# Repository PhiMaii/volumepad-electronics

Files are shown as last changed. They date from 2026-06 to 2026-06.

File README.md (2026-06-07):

# VolumePad STM32 PCB

Custom STM32-based PCB for the VolumePad project.

This board is intended for a haptic rotary input device with BLDC motor feedback, magnetic angle sensing, RGB LEDs, USB-C, buttons, strain sensing, and optional display support.

## Project status

Work in progress.

The current active development branch is `v2-redesign`.

The old version is kept on `v1-old`.

## Repository structure

    .
    ├── pcb/                 KiCad project files
    ├── docs/                Generated documentation, ignored by Git
    ├── fabrication/         Generated manufacturing files, ignored by Git
    ├── scripts/             Helper scripts
    ├── config.kibot.yaml    KiBot output configuration
    └── .github/workflows/   GitHub Actions automation

## PCB features

Planned / included hardware:

- STM32F405RGT6 microcontroller
- USB-C power and USB FS device connection
- TMC6300 BLDC motor driver
- MT6701 magnetic angle sensor
- WS2812B / SK6812 addressable RGB LEDs
- HX711-based strain sensing
- SWD programming connector
- Optional SPI display connection
- 4-layer PCB stackup

## KiCad project

Open the KiCad project from:

    open pcb/volumepad-stm32-pcb.kicad_pro

Main project files:

    pcb/volumepad-stm32-pcb.kicad_pro
    pcb/volumepad-stm32-pcb.kicad_sch
    pcb/volumepad-stm32-pcb.kicad_pcb

## KiBot automation

This repo uses KiBot through GitHub Actions to automatically generate documentation and manufacturing files.

Generated outputs include:

- Schematic PDF
- Gerber files
- Drill files
- BOM
- Pick-and-place position files

The workflow runs on changes to the PCB project or KiBot configuration.

Generated files are uploaded as GitHub Actions artifacts and are not committed to the repository.

## Generated files

Local generated outputs may appear in:

    docs/
    fabrication/

These files are intentionally ignored by Git.

## Notes

This PCB is still under active development and should not be considered production-ready yet.

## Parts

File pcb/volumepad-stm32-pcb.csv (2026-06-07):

Reference | Qty | Value | DNP | Exclude from BOM | Exclude from Board | Footprint | Datasheet | LCSC
C201,C204,C207,C301,C302,C303,C304,C307,C310,C501,C502,C503,C505,C506,C601,C701,C703,C704,C705,C801,C802,C803,C804,C805,C806,C807,C808,C809,C810,C811,C812,C813,C814,C815,C816,C817,C818,C819,C820,C821,C822,C823,C824,C825,C826,C827,C828,C829,C830,C831,C832,C833,C834,C835,C901 | 55 | 100n |  |  |  | Capacitor_SMD:C_0603_1608Metric |  | C42405541
C202,C205,C206,C504,C507,C702 | 6 | 10u |  |  |  | Capacitor_SMD:C_0805_2012Metric
C203 | 1 | 47u |  |  |  | Capacitor_SMD:C_1206_3216Metric
C305 | 1 | 4u7 |  |  |  | Capacitor_SMD:C_0805_2012Metric
C306,C902 | 2 | 1u |  |  |  | Capacitor_SMD:C_0603_1608Metric
C308,C309 | 2 | 2u2 |  |  |  | Capacitor_SMD:C_0805_2012Metric
C311,C312 | 2 | 18p |  |  |  | Capacitor_SMD:C_0603_1608Metric
C602 | 1 | 470u |  |  |  | Capacitor_SMD:CP_Elec_6.3x5.8 | 10 V
C706 | 1 | 100u |  |  |  | Capacitor_SMD:CP_Elec_5x5.8
D201 | 1 | D_TVS |  |  |  | Diode_SMD:D_SOD-123 |  | C2445454
D202 | 1 | RED |  |  |  | LED_SMD:LED_0603_1608Metric
D301 | 1 | BLUE |  |  |  | LED_SMD:LED_0603_1608Metric
D701 | 1 | ORANGE |  |  |  | LED_SMD:LED_0603_1608Metric
D804,D805,D806,D807,D808,D809,D810,D811,D812,D813,D814,D815,D816,D817,D818,D819,D820,D821,D822,D823,D824,D825,D826,D827,D828,D829,D830,D831,D832,D833,D834,D835 | 32 | WS2812B-2020 |  |  |  | LED_SMD:LED_WS2812B-2020_PLCC4_2.0x2.0mm | https://cdn-shop.adafruit.com/product-files/4684/4684_WS2812B-2020_V1.3_EN.pdf
F201 | 1 | Polyfuse |  |  |  | Fuse:Fuse_1206_3216Metric
FB201 | 1 | 600R@100MHz 2A |  |  |  | Inductor_SMD:L_0805_2012Metric | BLM21PG600SN1D
FB202 | 1 | 600R@100MHz, >=200mA, 0603 |  |  |  | Inductor_SMD:L_0603_1608Metric
J401 | 1 | USB_C_Receptacle_USB2.0_14P |  |  |  | Connector_USB:USB_C_Receptacle_GCT_USB4105-xx-A_16P_TopMnt_Horizontal | https://www.usb.org/sites/default/files/documents/usb_type-c.zip
J701 | 1 | Conn_01x03_Pin |  |  |  | Connector_JST:JST_SH_SM03B-SRSS-TB_1x03-1MP_P1.00mm_Horizontal
L501 | 1 | 3u3 |  |  |  | Inductor_SMD:L_0805_2012Metric
LED801,LED802,LED803 | 3 | MX_SK6812MINI-E |  |  |  | PCM_marbastlib-mx:LED_MX_6028R
MX501,MX502,MX503 | 3 | MX_SW_solder |  |  |  | PCM_marbastlib-mx:SW_MX_1u
Q501 | 1 | MMBT4403 |  |  |  | Package_TO_SOT_SMD:SOT-23
Q901 | 1 | AO3400A |  |  |  | Package_TO_SOT_SMD:SOT-23 | http://www.aosmd.com/pdfs/datasheet/AO3400A.pdf
R201 | 1 | 1k5 |  |  |  | Resistor_SMD:R_0603_1608Metric
R301,R302,R501,R504,R702,R901,R902 | 7 | 10k |  |  |  | Resistor_SMD:R_0603_1608Metric
R303,R304,R305,R306 | 4 | 22 |  |  |  | Resistor_SMD:R_0603_1608Metric
R307 | 1 | 1.5k |  |  |  | Resistor_SMD:R_0603_1608Metric
R401,R402 | 2 | 5k1 |  |  |  | Resistor_SMD:R_0603_1608Metric
R502,R503 | 2 | 100R |  |  |  | Resistor_SMD:R_0603_1608Metric
R505 | 1 | 8k2 |  |  |  | Resistor_SMD:R_0603_1608Metric
R601 | 1 | 330R |  |  |  | Resistor_SMD:R_0603_1608Metric
R701 | 1 | 2k2 |  |  |  | Resistor_SMD:R_0603_1608Metric
R703,R704,R705,R706,R707,R708,R710,R907 | 8 | 100k |  |  |  | Resistor_SMD:R_0603_1608Metric
R709,R903,R904,R905,R906 | 5 | 100 |  |  |  | Resistor_SMD:R_0603_1608Metric
RSG501,RSG502,RSG503,RSG504 | 4 | 330R |  |  |  | Resistor_SMD:R_2512_6332Metric
SW301 | 1 | RESET |  |  |  | Button_Switch_SMD:SW_Push_SPST_NO_Alps_SKRK
SW302 | 1 | BOOT0 |  |  |  | Button_Switch_SMD:SW_Push_SPST_NO_Alps_SKRK
U202 | 1 | AP1117-33 |  |  |  | Package_TO_SOT_SMD:SOT-223-3_TabPin2 | http://www.diodes.com/datasheets/AP1117.pdf
U301 | 1 | STM32F405RGTx |  |  |  | Package_QFP:LQFP-64_10x10mm_P0.5mm | https://www.st.com/resource/en/datasheet/stm32f405rg.pdf
U401 | 1 | USBLC6-2SC6 |  |  |  | Package_TO_SOT_SMD:SOT-23-6 | https://www.st.com/resource/en/datasheet/usblc6-2.pdf
U501 | 1 | MT6701CT |  |  |  | Package_SO:SO-8_3.9x4.9mm_P1.27mm | https://www.magntek.com.cn/upload/MT6701_Rev.1.5.pdf
U502 | 1 | HX711 |  |  |  | Package_SO:SOIC-16_3.9x9.9mm_P1.27mm | https://web.archive.org/web/20220615044707/https://akizukidenshi.com/download/ds/avia/hx711.pdf
U601 | 1 | 74AHCT1G125 |  |  |  | Package_TO_SOT_SMD:SOT-23-5 | http://www.ti.com/lit/sg/scyt129e/scyt129e.pdf
U701 | 1 | TMC6300-LA |  |  |  | TMC6300:QFN40P300X300X90-21N
Y301 | 1 | 8 MHz |  |  |  | Crystal:Crystal_SMD_3225-4Pin_3.2x2.5mm

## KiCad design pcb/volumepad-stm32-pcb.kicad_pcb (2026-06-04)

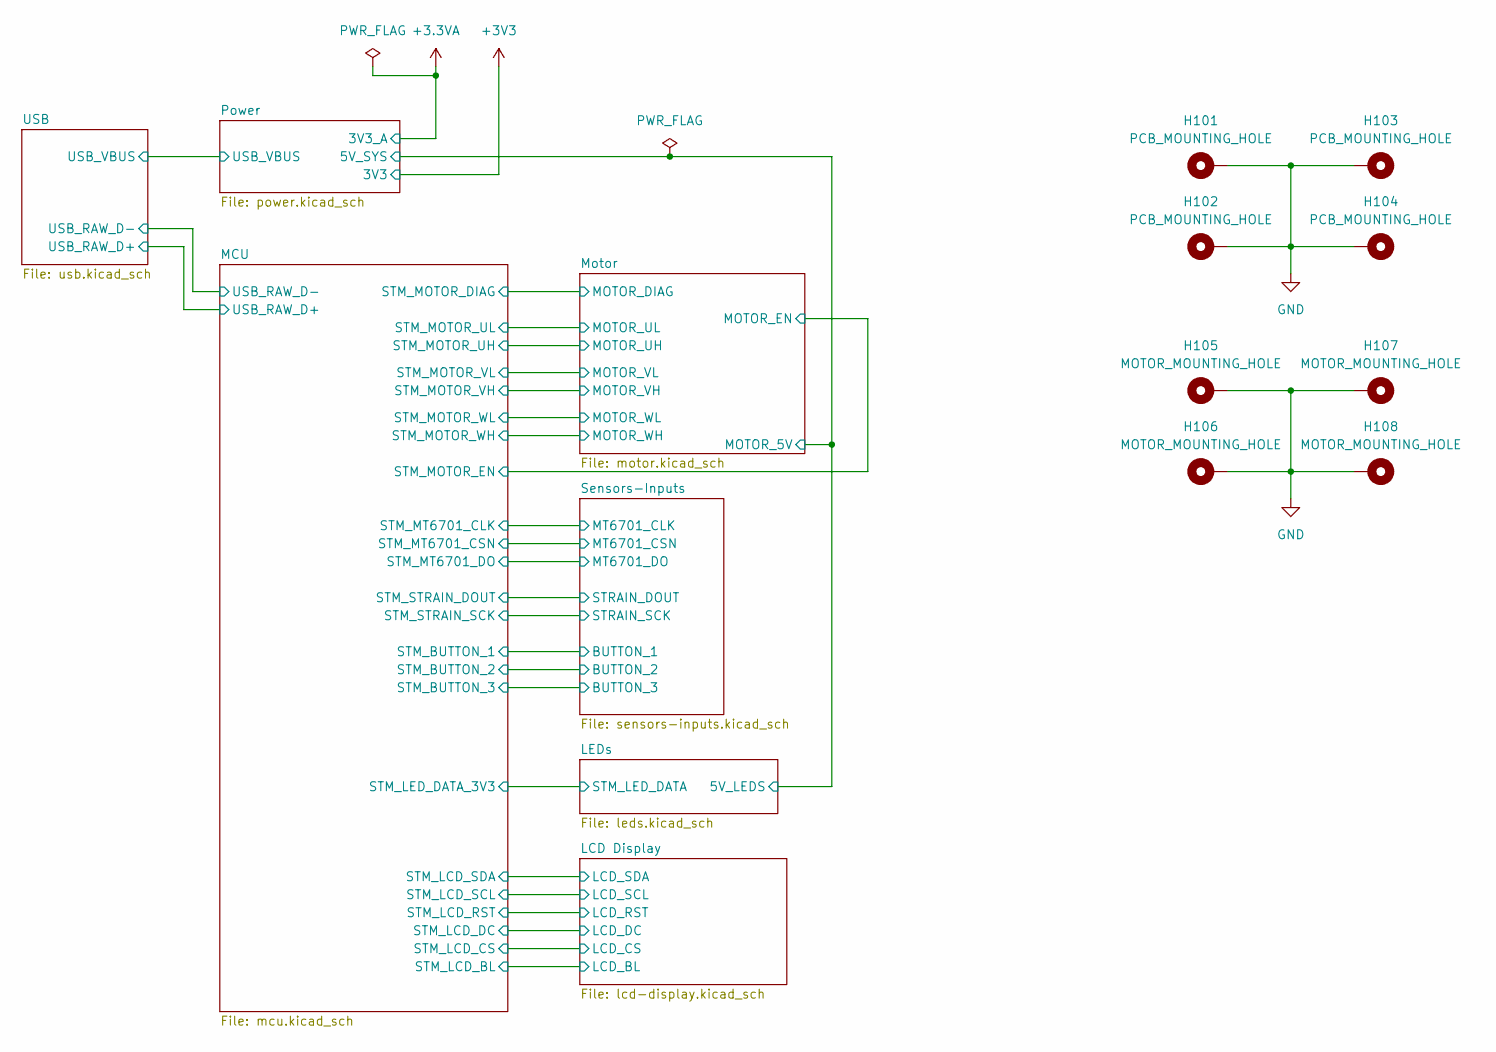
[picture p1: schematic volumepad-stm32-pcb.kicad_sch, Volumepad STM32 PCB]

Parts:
H101, H102, H103, H104: PCB_MOUNTING_HOLE; MountingHole_3mm_Pad_Via
H105, H106, H107, H108: MOTOR_MOUNTING_HOLE; MountingHole_2.5mm_Pad_Via

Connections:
GND: H101.1 (1_1), H102.1 (1_1), H103.1 (1_1), H104.1 (1_1), H105.1 (1_1), H106.1 (1_1), H107.1 (1_1), H108.1 (1_1); also elsewhere on the board

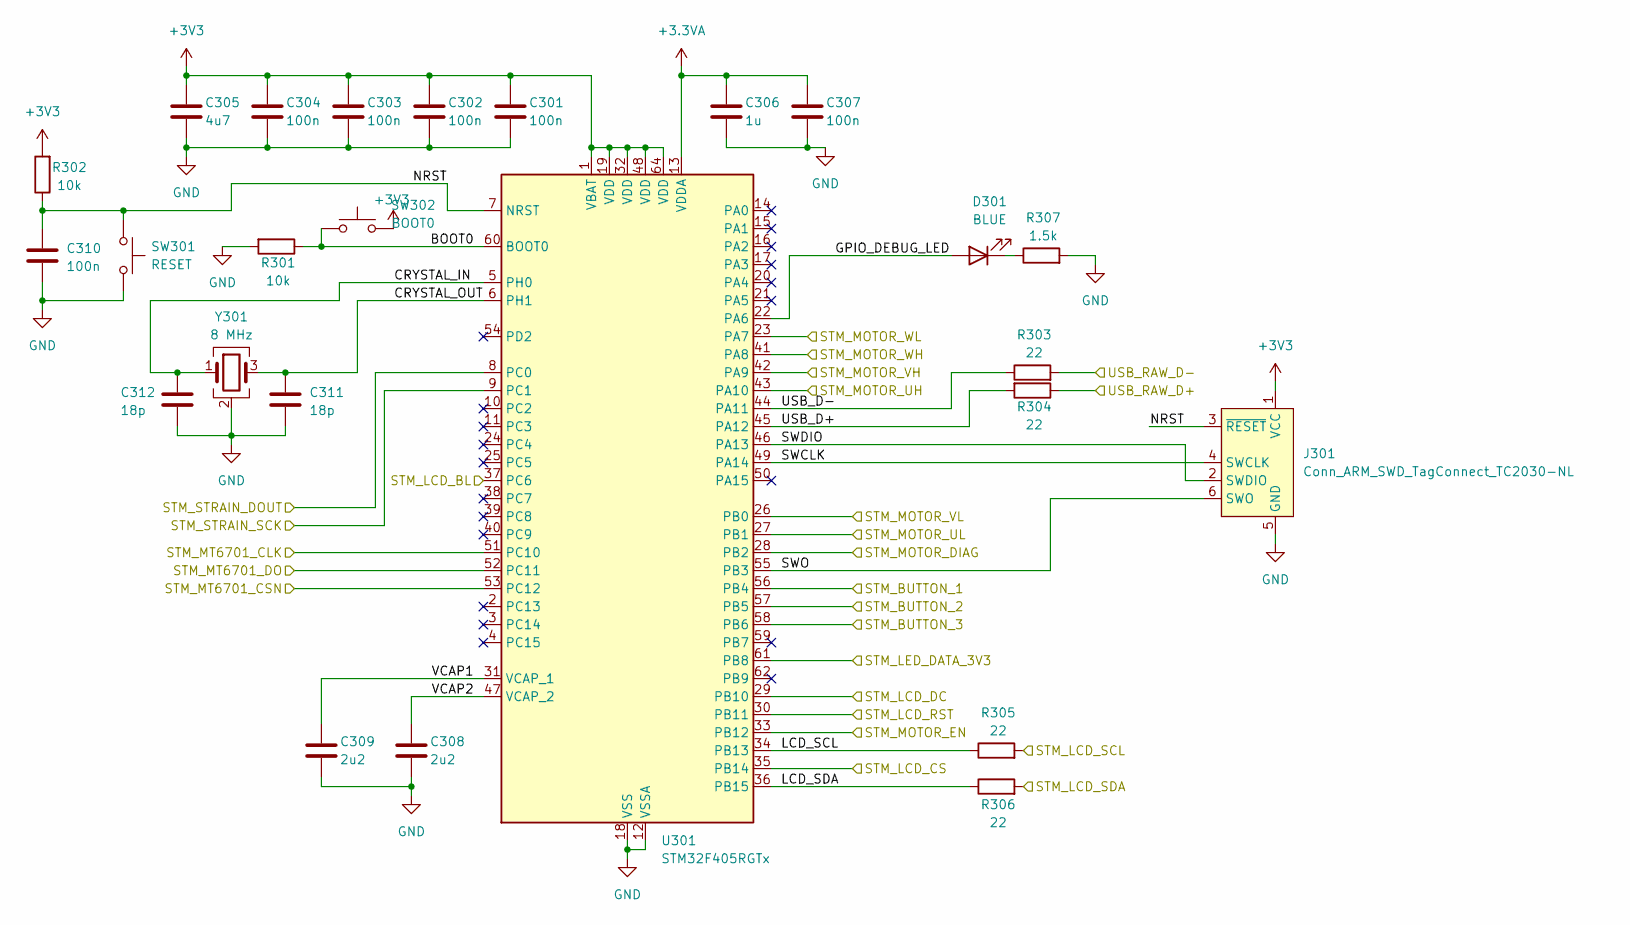
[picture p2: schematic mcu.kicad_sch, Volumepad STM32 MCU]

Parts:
C301, C302, C303, C304, C307, C310: 100n; C_0603_1608Metric; LCSC C42405541
C305: 4u7; C_0805_2012Metric
C306: 1u; C_0603_1608Metric
C308, C309: 2u2; C_0805_2012Metric
C311, C312: 18p; C_0603_1608Metric
D301: BLUE; LED_0603_1608Metric
J301: Conn_ARM_SWD_TagConnect_TC2030-NL; Tag-Connect_TC2030-IDC-NL_2x03_P1.27mm_Vertical
R301, R302: 10k; R_0603_1608Metric
R303, R304, R305, R306: 22; R_0603_1608Metric
R307: 1.5k; R_0603_1608Metric
SW301: RESET; SW_Push_SPST_NO_Alps_SKRK
SW302: BOOT0; SW_Push_SPST_NO_Alps_SKRK
U301: STM32F405RGTx; LQFP-64_10x10mm_P0.5mm; LCSC Part # C15742
Y301: 8 MHz; Crystal_SMD_3225-4Pin_3.2x2.5mm

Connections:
+3.3VA: C306.1, C307.1, U301.13 (VDDA); also elsewhere on the board
+3V3: C301.1, C302.1, C303.1, C304.1, C305.1, J301.1 (VCC), R302.2, SW302.1, U301.1 (VBAT), U301.19 (VDD), U301.32 (VDD), U301.48 (VDD), U301.64 (VDD); also elsewhere on the board
/LCD Display/LCD_BL: U301.37 (PC6); also elsewhere on the board
/LCD Display/LCD_CS: U301.35 (PB14); also elsewhere on the board
/LCD Display/LCD_DC: U301.29 (PB10); also elsewhere on the board
/LCD Display/LCD_RST: U301.30 (PB11); also elsewhere on the board
/LCD Display/LCD_SCL: R305.2; also elsewhere on the board
/LCD Display/LCD_SDA: R306.2; also elsewhere on the board
/LEDs/STM_LED_DATA: U301.61 (PB8); also elsewhere on the board
/MCU/BOOT0: R301.1, SW302.2, U301.60 (BOOT0)
/MCU/CRYSTAL_IN: C312.2, U301.5 (PH0), Y301.1
/MCU/CRYSTAL_OUT: C311.1, U301.6 (PH1), Y301.3
/MCU/GPIO_DEBUG_LED: D301.2 (A), U301.22 (PA6)
/MCU/LCD_SCL: R305.1, U301.34 (PB13)
/MCU/LCD_SDA: R306.1, U301.36 (PB15)
/MCU/NRST: C310.1, J301.3 (~RESET), R302.1, SW301.1, U301.7 (NRST)
/MCU/STM_BUTTON_1: U301.56 (PB4); also elsewhere on the board
/MCU/STM_BUTTON_2: U301.57 (PB5); also elsewhere on the board
/MCU/STM_BUTTON_3: U301.58 (PB6); also elsewhere on the board
/MCU/STM_MOTOR_EN: U301.33 (PB12); also elsewhere on the board
/MCU/STM_MOTOR_UH: U301.43 (PA10); also elsewhere on the board
/MCU/STM_MOTOR_UL: U301.27 (PB1); also elsewhere on the board
/MCU/STM_MOTOR_VH: U301.42 (PA9); also elsewhere on the board
/MCU/STM_MOTOR_VL: U301.26 (PB0); also elsewhere on the board
/MCU/STM_MOTOR_WH: U301.41 (PA8); also elsewhere on the board
/MCU/STM_MOTOR_WL: U301.23 (PA7); also elsewhere on the board
/MCU/STM_MT6701_CLK: U301.51 (PC10); also elsewhere on the board
/MCU/STM_MT6701_CSN: U301.53 (PC12); also elsewhere on the board
/MCU/STM_MT6701_DO: U301.52 (PC11); also elsewhere on the board
/MCU/STM_STRAIN_DOUT: U301.8 (PC0); also elsewhere on the board
/MCU/STM_STRAIN_SCK: U301.9 (PC1); also elsewhere on the board
/MCU/SWCLK: J301.4 (SWCLK), U301.49 (PA14)
/MCU/SWDIO: J301.2 (SWDIO), U301.46 (PA13)
/MCU/SWO: J301.6 (SWO), U301.55 (PB3)
/MCU/USB_D+: R304.2, U301.45 (PA12)
/MCU/USB_D-: R303.1, U301.44 (PA11)
/MCU/USB_RAW_D+: R304.1; also elsewhere on the board
/MCU/USB_RAW_D-: R303.2; also elsewhere on the board
/MCU/VCAP1: C309.1, U301.31 (VCAP_1)
/MCU/VCAP2: C308.1, U301.47 (VCAP_2)
/Motor/MOTOR_DIAG: U301.28 (PB2); also elsewhere on the board
GND: C301.2, C302.2, C303.2, C304.2, C305.2, C306.2, C307.2, C308.2, C309.2, C310.2, C311.2, C312.1, J301.5 (GND), R301.2, R307.2, SW301.2, U301.12 (VSSA), U301.18 (VSS), U301.63 (VSS), Y301.2 (G), Y301.4 (G); also elsewhere on the board
unnamed: D301.1 (K), R307.1

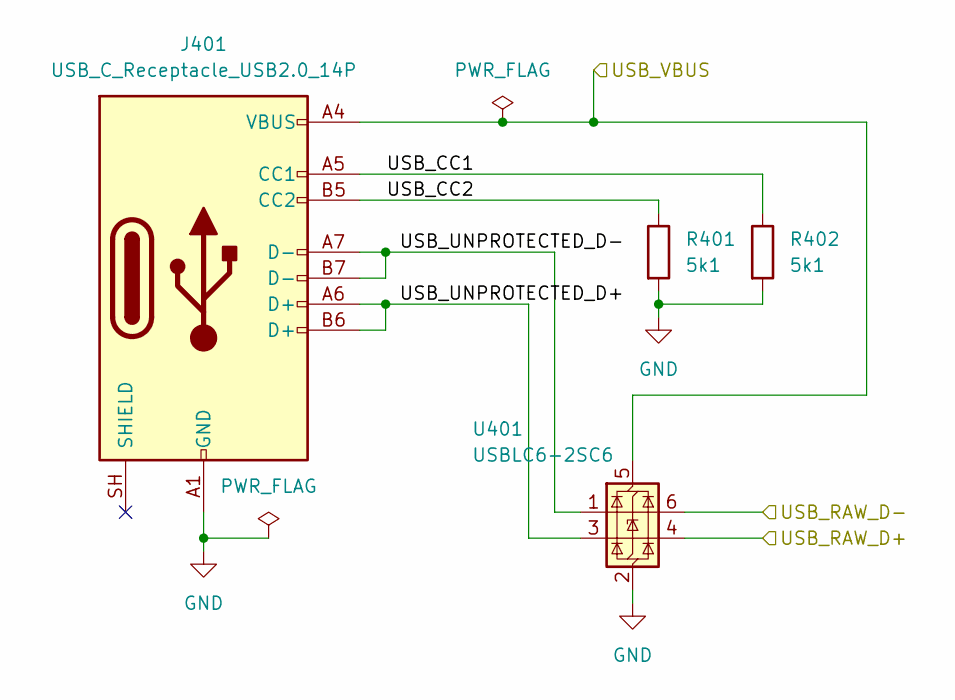
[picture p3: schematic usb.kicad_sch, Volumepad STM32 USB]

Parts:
J401: USB_C_Receptacle_USB2.0_14P; USB_C_Receptacle_GCT_USB4105-xx-A_16P_TopMnt_Horizontal
R401, R402: 5k1; R_0603_1608Metric
U401: USBLC6-2SC6; SOT-23-6

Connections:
/MCU/USB_RAW_D+: U401.4 (I/O2); also elsewhere on the board
/MCU/USB_RAW_D-: U401.6 (I/O1); also elsewhere on the board
/Power/USB_VBUS: J401.A4 (VBUS), J401.A9 (VBUS), J401.B4 (VBUS), J401.B9 (VBUS), U401.5 (VBUS); also elsewhere on the board
/USB/USB_CC1: J401.A5 (CC1), R402.1
/USB/USB_CC2: J401.B5 (CC2), R401.1
/USB/USB_UNPROTECTED_D+: J401.A6 (D+), J401.B6 (D+), U401.3 (I/O2)
/USB/USB_UNPROTECTED_D-: J401.A7 (D-), J401.B7 (D-), U401.1 (I/O1)
GND: J401.A1 (GND), J401.A12 (GND), J401.B1 (GND), J401.B12 (GND), R401.2, R402.2, U401.2 (GND); also elsewhere on the board

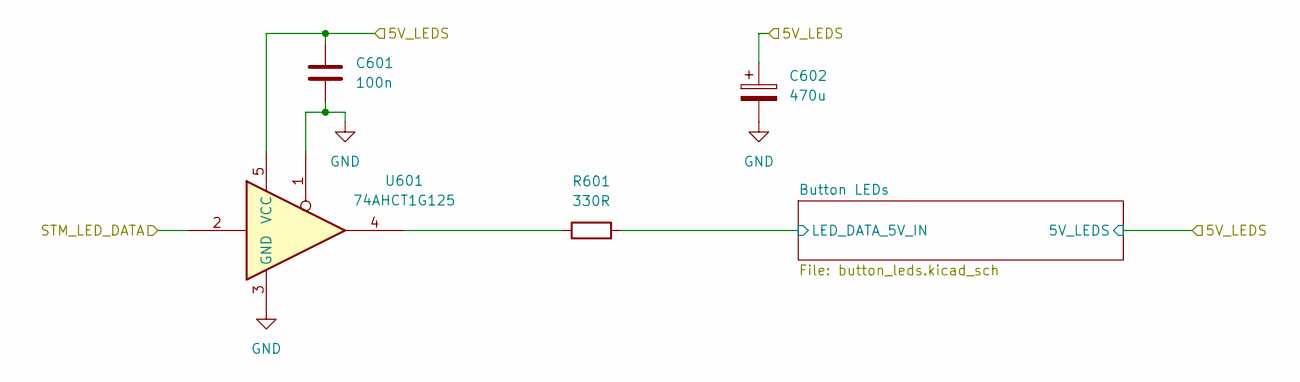
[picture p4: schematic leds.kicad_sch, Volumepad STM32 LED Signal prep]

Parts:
C601: 100n; C_0603_1608Metric; LCSC C42405541
C602: 470u; CP_Elec_6.3x5.8
R601: 330R; R_0603_1608Metric
U601: 74AHCT1G125; SOT-23-5

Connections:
/LEDs/Button LEDs/LED_DATA_5V_IN: R601.2; also elsewhere on the board
/LEDs/STM_LED_DATA: U601.2; also elsewhere on the board
/Power/5V_SYS: C601.1, C602.1, U601.5 (VCC); also elsewhere on the board
GND: C601.2, C602.2, U601.1, U601.3 (GND); also elsewhere on the board
unnamed: R601.1, U601.4

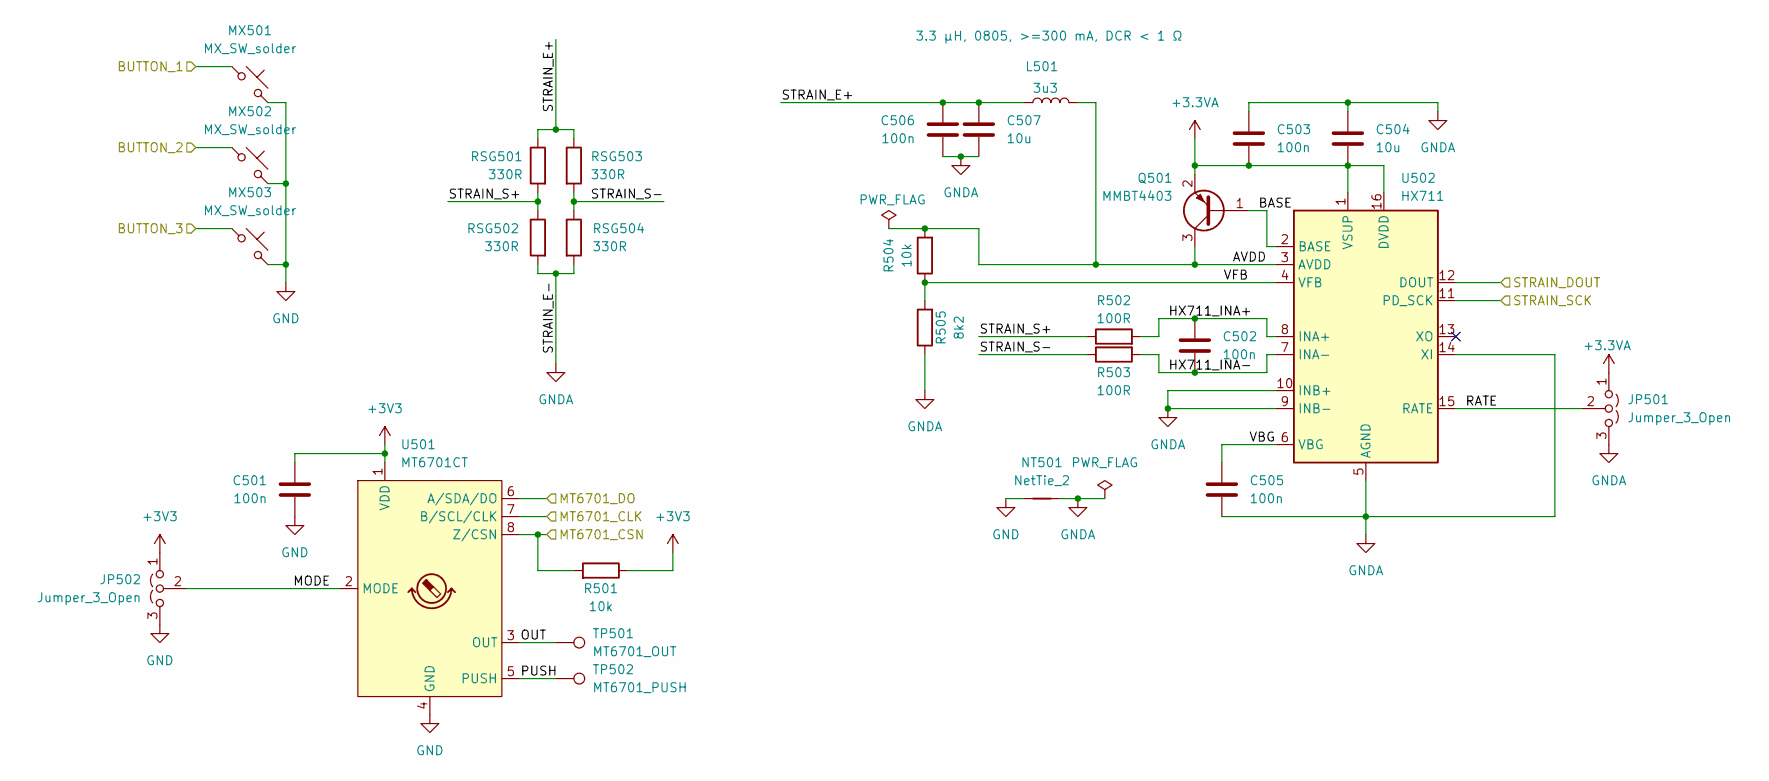
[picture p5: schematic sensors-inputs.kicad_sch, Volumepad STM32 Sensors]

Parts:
C501, C502, C503, C505, C506: 100n; C_0603_1608Metric; LCSC C42405541
C504, C507: 10u; C_0805_2012Metric
JP501, JP502: Jumper_3_Open; SolderJumper-3_P1.3mm_Open_RoundedPad1.0x1.5mm
L501: 3u3; L_0805_2012Metric
MX501, MX502, MX503: MX_SW_solder; SW_MX_1u
NT501: NetTie_2; NetTie-2_SMD_Pad0.5mm
Q501: MMBT4403; SOT-23
R501, R504: 10k; R_0603_1608Metric
R502, R503: 100R; R_0603_1608Metric
R505: 8k2; R_0603_1608Metric
RSG501, RSG502, RSG503, RSG504: 330R; R_2512_6332Metric
TP501: MT6701_OUT; TestPoint_Pad_D1.0mm
TP502: MT6701_PUSH; TestPoint_Pad_D1.0mm
U501: MT6701CT; SO-8_3.9x4.9mm_P1.27mm
U502: HX711; SOIC-16_3.9x9.9mm_P1.27mm

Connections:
+3.3VA: C503.2, C504.2, JP501.1 (A), Q501.2 (E), U502.1 (VSUP), U502.16 (DVDD); also elsewhere on the board
+3V3: C501.1, JP502.1 (A), R501.1, U501.1 (VDD); also elsewhere on the board
/MCU/STM_BUTTON_1: MX501.1; also elsewhere on the board
/MCU/STM_BUTTON_2: MX502.1; also elsewhere on the board
/MCU/STM_BUTTON_3: MX503.1; also elsewhere on the board
/MCU/STM_MT6701_CLK: U501.7 (B/SCL/CLK); also elsewhere on the board
/MCU/STM_MT6701_CSN: R501.2, U501.8 (Z/CSN); also elsewhere on the board
/MCU/STM_MT6701_DO: U501.6 (A/SDA/DO); also elsewhere on the board
/MCU/STM_STRAIN_DOUT: U502.12 (DOUT); also elsewhere on the board
/MCU/STM_STRAIN_SCK: U502.11 (PD_SCK); also elsewhere on the board
/Sensors-Inputs/AVDD: L501.1, Q501.3 (C), R504.2, U502.3 (AVDD)
/Sensors-Inputs/BASE: Q501.1 (B), U502.2 (BASE)
/Sensors-Inputs/HX711_INA+: C502.1, R502.2, U502.8 (INA+)
/Sensors-Inputs/HX711_INA-: C502.2, R503.2, U502.7 (INA-)
/Sensors-Inputs/MODE: JP502.2 (C), U501.2 (MODE)
/Sensors-Inputs/OUT: TP501.1 (1_1), U501.3 (OUT)
/Sensors-Inputs/PUSH: TP502.1 (1_1), U501.5 (PUSH)
/Sensors-Inputs/RATE: JP501.2 (C), U502.15 (RATE)
/Sensors-Inputs/STRAIN_E+: C506.1, C507.1, L501.2, RSG501.1, RSG503.1
/Sensors-Inputs/STRAIN_S+: R502.1, RSG501.2, RSG502.1
/Sensors-Inputs/STRAIN_S-: R503.1, RSG503.2, RSG504.1
/Sensors-Inputs/VBG: C505.1, U502.6 (VBG)
/Sensors-Inputs/VFB: R504.1, R505.2, U502.4 (VFB)
GND: C501.2, JP502.3 (B), MX501.2, MX502.2, MX503.2, NT501.1, U501.4 (GND); also elsewhere on the board
GNDA: C503.1, C504.1, C505.2, C506.2, C507.2, JP501.3 (B), NT501.2, R505.1, RSG502.2, RSG504.2, U502.5 (AGND), U502.9 (INB-), U502.10 (INB+), U502.14 (XI)

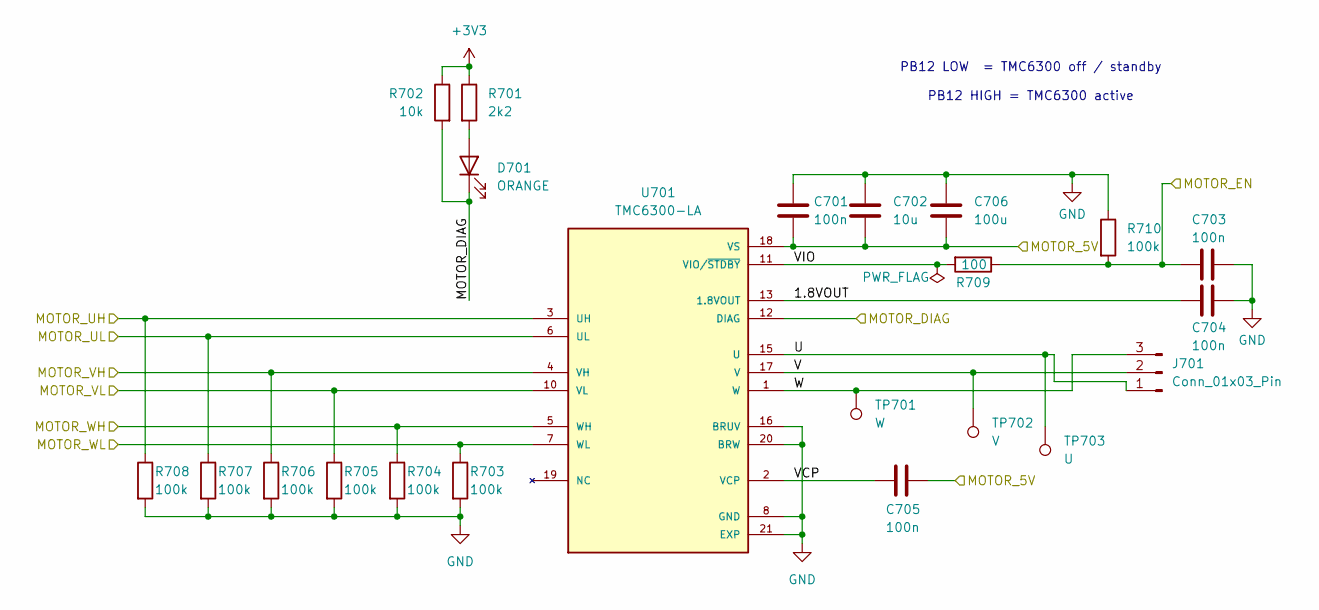
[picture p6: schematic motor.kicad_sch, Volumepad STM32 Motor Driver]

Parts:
C701, C703, C704, C705: 100n; C_0603_1608Metric
C702: 10u; C_0805_2012Metric
C706: 100u; CP_Elec_5x5.8
D701: ORANGE; LED_0603_1608Metric
J701: Conn_01x03_Pin; JST_SH_SM03B-SRSS-TB_1x03-1MP_P1.00mm_Horizontal
R701: 2k2; R_0603_1608Metric
R702: 10k; R_0603_1608Metric
R703, R704, R705, R706, R707, R708, R710: 100k; R_0603_1608Metric
R709: 100; R_0603_1608Metric
TP701: W; TestPoint_Pad_D1.0mm
TP702: V; TestPoint_Pad_D1.0mm
TP703: U; TestPoint_Pad_D1.0mm
U701: TMC6300-LA; QFN40P300X300X90-21N; PARTREV 1.08

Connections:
+3V3: R701.1, R702.1; also elsewhere on the board
/MCU/STM_MOTOR_EN: C703.1, R709.1, R710.2; also elsewhere on the board
/MCU/STM_MOTOR_UH: R708.1, U701.3 (UH); also elsewhere on the board
/MCU/STM_MOTOR_UL: R707.1, U701.6 (UL); also elsewhere on the board
/MCU/STM_MOTOR_VH: R706.1, U701.4 (VH); also elsewhere on the board
/MCU/STM_MOTOR_VL: R705.1, U701.10 (VL); also elsewhere on the board
/MCU/STM_MOTOR_WH: R704.1, U701.5 (WH); also elsewhere on the board
/MCU/STM_MOTOR_WL: R703.1, U701.7 (WL); also elsewhere on the board
/Motor/1.8VOUT: C704.2, U701.13 (1.8VOUT)
/Motor/MOTOR_DIAG: D701.1 (K), R702.2, U701.12 (DIAG); also elsewhere on the board
/Motor/U: J701.1, TP703.1 (1_1), U701.15 (U)
/Motor/V: J701.2, TP702.1 (1_1), U701.17 (V)
/Motor/VCP: C705.1, U701.2 (VCP)
/Motor/VIO: R709.2, U701.11 (VIO/~STDBY)
/Motor/W: J701.3, TP701.1 (1_1), U701.1 (W)
/Power/5V_SYS: C701.2, C702.2, C705.2, C706.2, U701.18 (VS); also elsewhere on the board
GND: C701.1, C702.1, C703.2, C704.1, C706.1, R703.2, R704.2, R705.2, R706.2, R707.2, R708.2, R710.1, U701.8 (GND), U701.9 (GND), U701.14 (GND), U701.16 (BRUV), U701.20 (BRW), U701.21 (EXP); also elsewhere on the board
unnamed: D701.2 (A), R701.2

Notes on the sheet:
PB12 LOW = TMC6300 off / standby PB12 HIGH = TMC6300 active

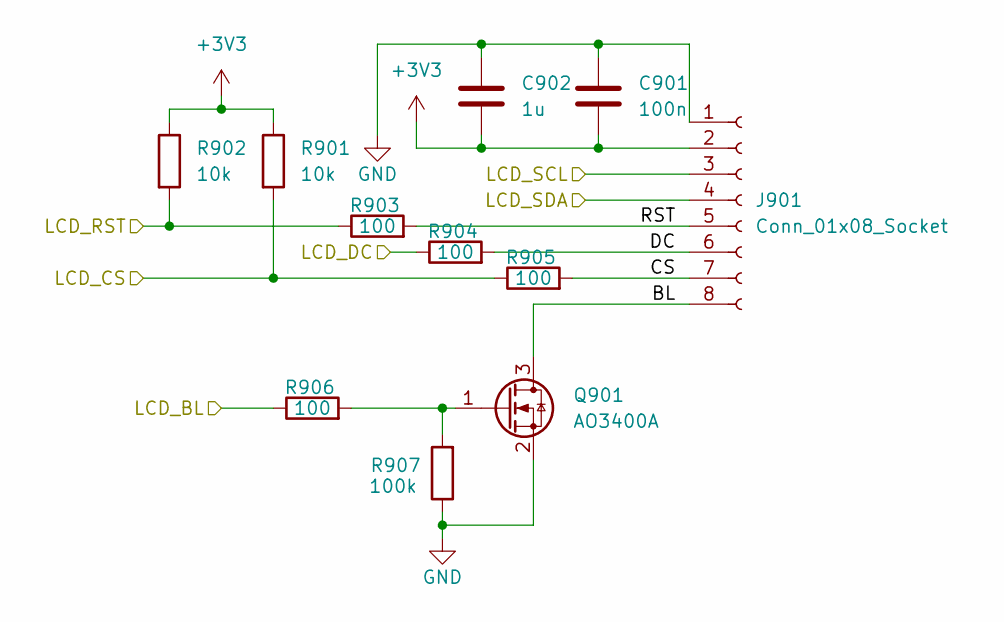
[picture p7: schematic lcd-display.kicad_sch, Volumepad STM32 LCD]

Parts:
C901: 100n; C_0603_1608Metric
C902: 1u; C_0603_1608Metric
J901: Conn_01x08_Socket; PinHeader_1x08_P2.54mm_Vertical
Q901: AO3400A; SOT-23
R901, R902: 10k; R_0603_1608Metric
R903, R904, R905, R906: 100; R_0603_1608Metric
R907: 100k; R_0603_1608Metric

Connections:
+3V3: C901.2, C902.2, J901.2 (VCC), R901.1, R902.1; also elsewhere on the board
/LCD Display/BL: J901.8 (BL), Q901.3 (D)
/LCD Display/CS: J901.7 (CS), R905.2
/LCD Display/DC: J901.6 (DC), R904.2
/LCD Display/LCD_BL: R906.1; also elsewhere on the board
/LCD Display/LCD_CS: R901.2, R905.1; also elsewhere on the board
/LCD Display/LCD_DC: R904.1; also elsewhere on the board
/LCD Display/LCD_RST: R902.2, R903.1; also elsewhere on the board
/LCD Display/LCD_SCL: J901.3 (SCL); also elsewhere on the board
/LCD Display/LCD_SDA: J901.4 (SDA); also elsewhere on the board
/LCD Display/RST: J901.5 (RST), R903.2
GND: C901.1, C902.1, J901.1 (GND), Q901.2 (S), R907.1; also elsewhere on the board
unnamed: Q901.1 (G), R906.2, R907.2

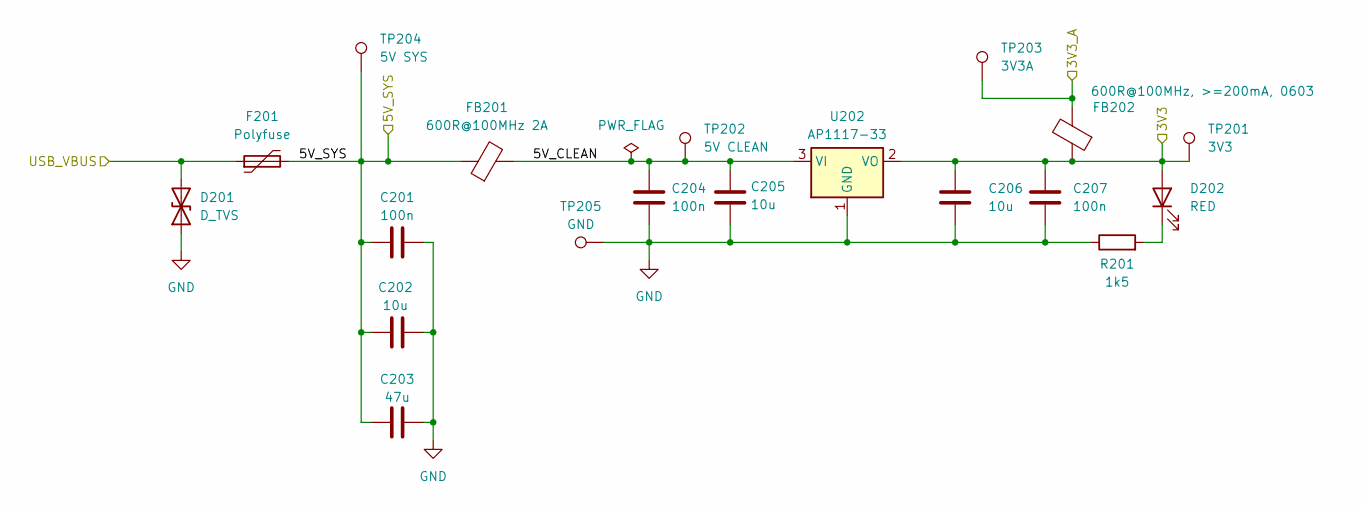
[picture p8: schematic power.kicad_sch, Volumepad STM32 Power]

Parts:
C201, C204, C207: 100n; C_0603_1608Metric; LCSC C42405541
C202, C205, C206: 10u; C_0805_2012Metric
C203: 47u; C_1206_3216Metric
D201: D_TVS; D_SOD-123; LCSC C2445454
D202: RED; LED_0603_1608Metric
F201: Polyfuse; Fuse_1206_3216Metric; LCSC Part # C70082
FB201: 600R@100MHz 2A; L_0805_2012Metric
FB202: 600R@100MHz, >=200mA, 0603; L_0603_1608Metric
R201: 1k5; R_0603_1608Metric
TP201: 3V3; TestPoint_Pad_D1.0mm
TP202: 5V CLEAN; TestPoint_Pad_D1.0mm
TP203: 3V3A; TestPoint_Pad_D1.0mm
TP204: 5V SYS; TestPoint_Pad_D1.0mm
TP205: GND; TestPoint_Pad_D1.0mm
U202: AP1117-33; SOT-223-3_TabPin2

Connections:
+3.3VA: FB202.2, TP203.1 (1_1); also elsewhere on the board
+3V3: C206.1, C207.2, D202.2 (A), FB202.1, TP201.1 (1_1), U202.2 (VO); also elsewhere on the board
/Power/5V_CLEAN: C204.1, C205.2, FB201.2, TP202.1 (1_1), U202.3 (VI)
/Power/5V_SYS: C201.1, C202.2, C203.2, F201.2, FB201.1, TP204.1 (1_1); also elsewhere on the board
/Power/USB_VBUS: D201.2 (A2), F201.1; also elsewhere on the board
GND: C201.2, C202.1, C203.1, C204.2, C205.1, C206.2, C207.1, D201.1 (A1), R201.1, TP205.1 (1_1), U202.1 (GND); also elsewhere on the board
unnamed: D202.1 (K), R201.2

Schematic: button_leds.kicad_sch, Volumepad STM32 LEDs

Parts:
C801, C802, C803, C804, C805, C806, C807, C808, C809, C810, C811, C812, C813: 100n; C_0603_1608Metric; LCSC C42405541
C814, C815, C816, C817, C818, C819, C820, C821, C822, C823, C824, C825, C826, C827, C828, C829, C830, C831, C832, C833, C834, C835: 100n; C_0603_1608Metric
D804, D805, D806, D807, D808, D809, D810, D811, D812, D813, D814, D815, D816, D817, D818, D819, D820, D821, D822, D823, D824, D825, D826, D827, D828, D829, D830, D831, D832, D833, D834, D835: WS2812B-2020; LED_WS2812B-2020_PLCC4_2.0x2.0mm
LED801, LED802, LED803: MX_SK6812MINI-E; LED_MX_6028R

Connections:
/LEDs/Button LEDs/LED_DATA_5V_IN: LED801.3 (DIN); also elsewhere on the board
/LEDs/Button LEDs/LED_DATA_5V_OUT: D804.3 (DIN), LED803.2 (DOUT)
/Power/5V_SYS: C801.1, C802.1, C803.1, C804.1, C805.1, C806.1, C807.1, C808.1, C809.1, C810.1, C811.1, C812.1, C813.1, C814.1, C815.1, C816.1, C817.1, C818.1, C819.1, C820.1, C821.1, C822.1, C823.1, C824.1, C825.1, C826.1, C827.1, C828.1, C829.1, C830.1, C831.1, C832.1, C833.1, C834.1, C835.1, D804.4 (VDD), D805.4 (VDD), D806.4 (VDD), D807.4 (VDD), D808.4 (VDD), D809.4 (VDD), D810.4 (VDD), D811.4 (VDD), D812.4 (VDD), D813.4 (VDD), D814.4 (VDD), D815.4 (VDD), D816.4 (VDD), D817.4 (VDD), D818.4 (VDD), D819.4 (VDD), D820.4 (VDD), D821.4 (VDD), D822.4 (VDD), D823.4 (VDD), D824.4 (VDD), D825.4 (VDD), D826.4 (VDD), D827.4 (VDD), D828.4 (VDD), D829.4 (VDD), D830.4 (VDD), D831.4 (VDD), D832.4 (VDD), D833.4 (VDD), D834.4 (VDD), D835.4 (VDD), LED801.1 (VDD), LED802.1 (VDD), LED803.1 (VDD); also elsewhere on the board
GND: C801.2, C802.2, C803.2, C804.2, C805.2, C806.2, C807.2, C808.2, C809.2, C810.2, C811.2, C812.2, C813.2, C814.2, C815.2, C816.2, C817.2, C818.2, C819.2, C820.2, C821.2, C822.2, C823.2, C824.2, C825.2, C826.2, C827.2, C828.2, C829.2, C830.2, C831.2, C832.2, C833.2, C834.2, C835.2, D804.2 (VSS), D805.2 (VSS), D806.2 (VSS), D807.2 (VSS), D808.2 (VSS), D809.2 (VSS), D810.2 (VSS), D811.2 (VSS), D812.2 (VSS), D813.2 (VSS), D814.2 (VSS), D815.2 (VSS), D816.2 (VSS), D817.2 (VSS), D818.2 (VSS), D819.2 (VSS), D820.2 (VSS), D821.2 (VSS), D822.2 (VSS), D823.2 (VSS), D824.2 (VSS), D825.2 (VSS), D826.2 (VSS), D827.2 (VSS), D828.2 (VSS), D829.2 (VSS), D830.2 (VSS), D831.2 (VSS), D832.2 (VSS), D833.2 (VSS), D834.2 (VSS), D835.2 (VSS), LED801.4 (VSS), LED802.4 (VSS), LED803.4 (VSS); also elsewhere on the board
unnamed: D804.1 (DOUT), D805.3 (DIN)
unnamed: D805.1 (DOUT), D806.3 (DIN)
unnamed: D806.1 (DOUT), D807.3 (DIN)
unnamed: D807.1 (DOUT), D808.3 (DIN)
unnamed: D808.1 (DOUT), D809.3 (DIN)
unnamed: D809.1 (DOUT), D810.3 (DIN)
unnamed: D810.1 (DOUT), D811.3 (DIN)
unnamed: D811.1 (DOUT), D812.3 (DIN)
unnamed: D812.1 (DOUT), D813.3 (DIN)
unnamed: D813.1 (DOUT), D814.3 (DIN)
unnamed: D814.1 (DOUT), D815.3 (DIN)
unnamed: D815.1 (DOUT), D816.3 (DIN)
unnamed: D816.1 (DOUT), D817.3 (DIN)
unnamed: D817.1 (DOUT), D818.3 (DIN)
unnamed: D818.1 (DOUT), D819.3 (DIN)
unnamed: D819.1 (DOUT), D820.3 (DIN)
unnamed: D820.1 (DOUT), D821.3 (DIN)
unnamed: D821.1 (DOUT), D822.3 (DIN)
unnamed: D822.1 (DOUT), D823.3 (DIN)
unnamed: D823.1 (DOUT), D824.3 (DIN)
unnamed: D824.1 (DOUT), D825.3 (DIN)
unnamed: D825.1 (DOUT), D826.3 (DIN)
unnamed: D826.1 (DOUT), D827.3 (DIN)
unnamed: D827.1 (DOUT), D828.3 (DIN)
unnamed: D828.1 (DOUT), D829.3 (DIN)
unnamed: D829.1 (DOUT), D830.3 (DIN)
unnamed: D830.1 (DOUT), D831.3 (DIN)
unnamed: D831.1 (DOUT), D832.3 (DIN)
unnamed: D832.1 (DOUT), D833.3 (DIN)
unnamed: D833.1 (DOUT), D834.3 (DIN)
unnamed: D834.1 (DOUT), D835.3 (DIN)
unnamed: LED801.2 (DOUT), LED802.3 (DIN)
unnamed: LED802.2 (DOUT), LED803.3 (DIN)

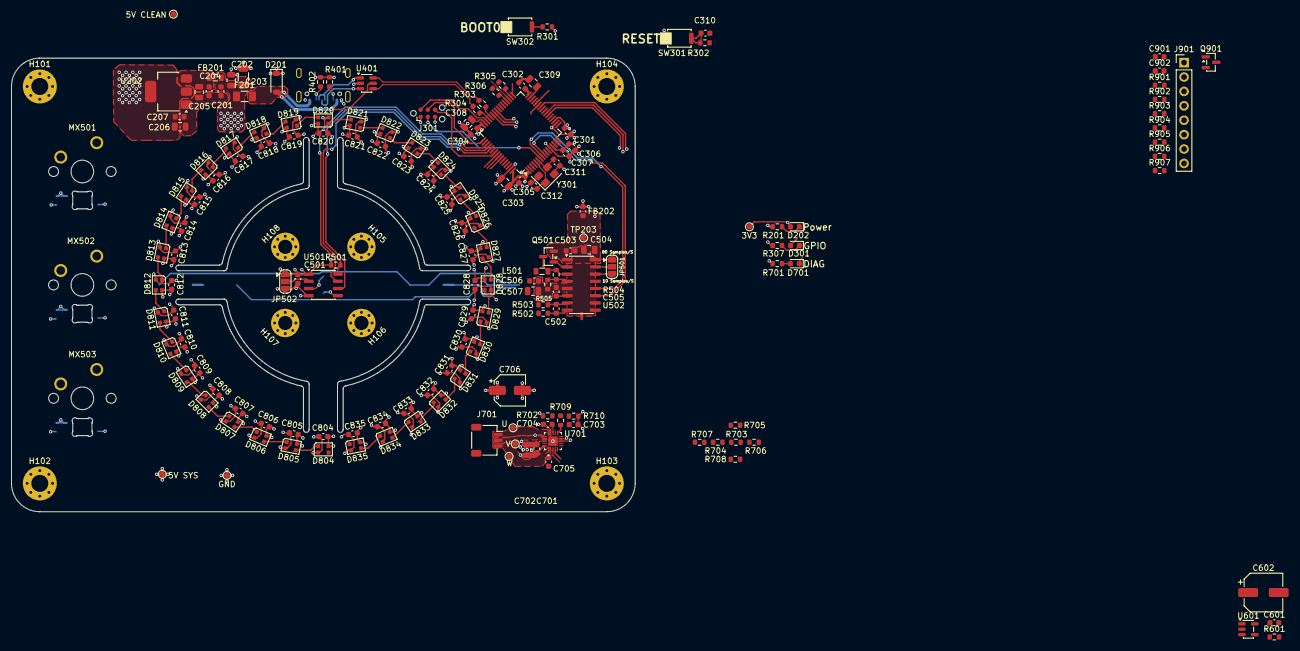
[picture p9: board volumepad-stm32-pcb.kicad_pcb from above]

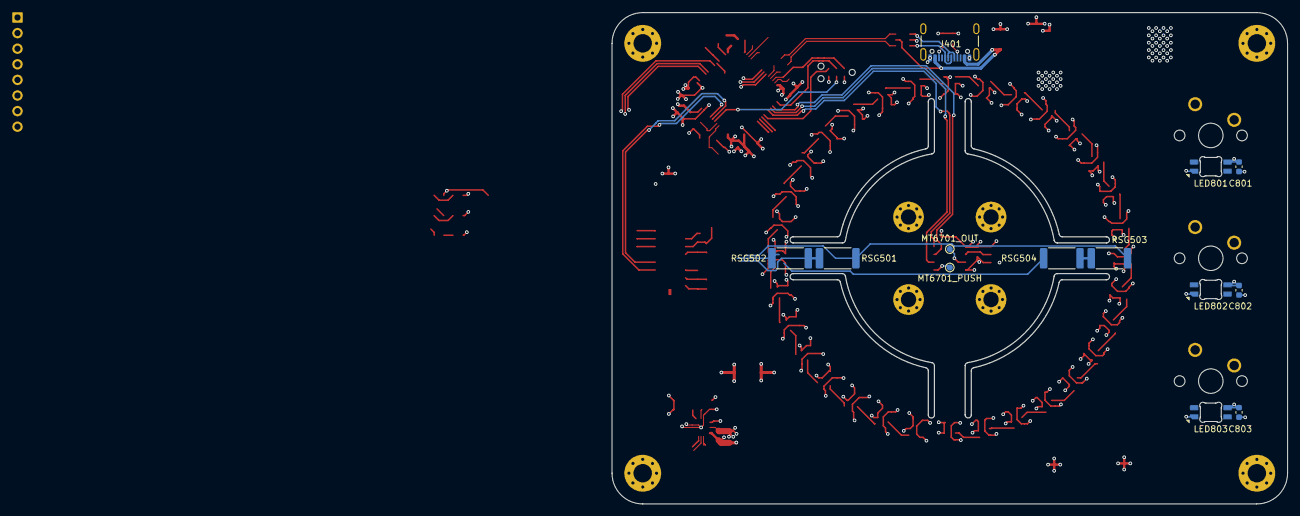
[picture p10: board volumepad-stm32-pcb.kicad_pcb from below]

Board: 4 copper layers, 110.0 x 80.0 mm, 191 parts (13 on the bottom side), 113 nets.

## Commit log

2026-06-04 Initial KiCad project commit
    [button_leds.kicad_sch, lcd-display.kicad_sch, leds.kicad_sch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]
2026-06-04 Updated footprints to inclue 3d models for the simulation
    [motor.kicad_sch, volumepad-stm32-pcb.kicad_pcb]
2026-06-07 Exported first BOM csv to test with LCSC
    [volumepad-stm32-pcb.csv]
2026-06-07 Started adding LCSC part numbers to make ordering the parts easier
    [button_leds.kicad_sch, lcd-display.kicad_sch, leds.kicad_sch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]
2026-06-07 Added folder for 3d models for the 3D pcb viewer
2026-06-07 Move KiCad project into pcb folder
    [button_leds.kicad_sch, lcd-display.kicad_sch, leds.kicad_sch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]
2026-06-07 Use KiCad 10 for KiBot workflow
